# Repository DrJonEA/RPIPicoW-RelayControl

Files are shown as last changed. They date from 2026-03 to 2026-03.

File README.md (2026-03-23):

# DrJonEA: RPIPicoW-RelayControl

A Raspberry Pi Pico W based Relay control board. Using a ULN2003 as driver for a 5Volt Relay.

Example controlling the Relay via an onboard SPST switch. Plus remote control of MQTT/TLS.

This project is featured on my [Youtube Channel DrJonEA](https://youtube.com/@drjonea).

## Clone and Build
The example is built  using the Pico SDK version 2.2.0 and a number of libraries which are included as submodules.
Please clone the repository using the recurse submodules switch. 

I've written a [blog post](https://drjonea.co.uk/2025/12/15/building-my-projects-from-repo/) on how to clone, build and 
debug my projects. It covers command line and VSCode build. I hope this help you get started.

## Schematic, PCB Design and Components
The *PCB* folder contains the KiCAD project files for the PCB Design. 

Components:

 |  Designator | Footprint | Quantity | Designation | 
 | ------------- | ----------- | ----------- | ------------ | 
 | "Id" | "Designator" | "Footprint" | "Quantity" | "Designation" | "Supplier and ref" | 
 | 1 | "C1" | "CP_Radial_D10.0mm_P5.00mm" | 1 | "1000uF" | 
 | 2 | "I2C2,I2C1" | "PinHeader_1x04_P2.54mm_Vertical" | 2 | "Conn_01x04_Pin" | 
 | 3 | "J4,J3" | "PinHeader_1x04_P2.54mm_Vertical" | 2 | "Touch Display" | 
 | 4 | "O1" | "ScrewTerm_Oiyagai_01x02_5mm" | 1 | "Elect" | 
 | 5 | "A1" | "RaspberryPi_Pico_Common_Unspecified" | 1 | "RaspberryPi_Pico" | 
 | 6 | "C2" | "C_Disc_D4.7mm_W2.5mm_P5.00mm" | 1 | "10uF" | 
 | 7 | "K1" | "Relay_SPDT_SANYOU_SRD_Series_Form_C" | 1 | "SANYOU_SRD_Form_C" |  |  | 
 | 8 | "ST1" | "ScrewTerm_Oiyagai_01x03_5mm" | 1 | "Screw_Terminal_01x03" | 
 | 9 | "U1" | "CERDIP-16_W7.62mm_SideBrazed_LongPads_Socket" | 1 | "ULN2003" | 
 | 10 | "D1" | "D_DO-41_SOD81_P10.16mm_Horizontal" | 1 | "1N4007" | 
 | 11 | "SW2" | "SW_PUSH_6mm" | 1 | "SW_SPST" | 
 | 12 | "SW1" | "SW_Latch_7x7_DPDT" | 1 | "SW_DPDT_x2" | 
 | 13 | "R4" | "R_Axial_DIN0309_L9.0mm_D3.2mm_P15.24mm_Horizontal" | 1 | "220R" | 
 | 14 | "U2" | "WS2812B Strip" | 1 | 4 LED strip at 144per meter fits | 

## Examples Projects

### exp/TestLeds
A test project to check the WS2812B LEDs and Switch on the board

### exp/TestRelay
A test projec to check the Relay works. Uses the switch to toggle the relay state. Shows the state of the
relay on the WS2812B LED

### Main Project
This is a MQTT device connecting to a MQTT Broker (I use Flespi.io). It connects over TLS using WolfSSL 
to provide a TLS connection.  The device will then take commands on the topic 
"TNG/*{DEVICEID}*/TPC/Relay/req". With a Payload as JSON saying {"on": True} or {"on": False}.

To build this examples the following environment variables are used to source credentials:

+ WIFI_SSID
+ WIFI_PASSWORD
+ MQTT_CLIENT
+ MQTT_USER
+ MQTT_PASSWD
+ MQTT_HOST
+ MQTT_PORT

I have a course showing how I build these types of MQTT Devices over on [Udemy](https://www.udemy.com/course/iot-with-rpi-pico-w/?referralCode=331C13FDD6ABC00BFB81).

### Python Control Example
Python scripts which can interact with the device are included in the *py* folder. They require the client id of
the device the are controlling in this form:

python3 on.py *{DEVICE_ID}*

The scripts take credentials for the client from the followin environment variables:

+ MQTT_USER
+ MQTT_PASSWD
+ MQTT_HOST
+ MQTT_PORT

NOTE: To use MQTT the device and the client must have different Client IDs (or MQTT_USER).

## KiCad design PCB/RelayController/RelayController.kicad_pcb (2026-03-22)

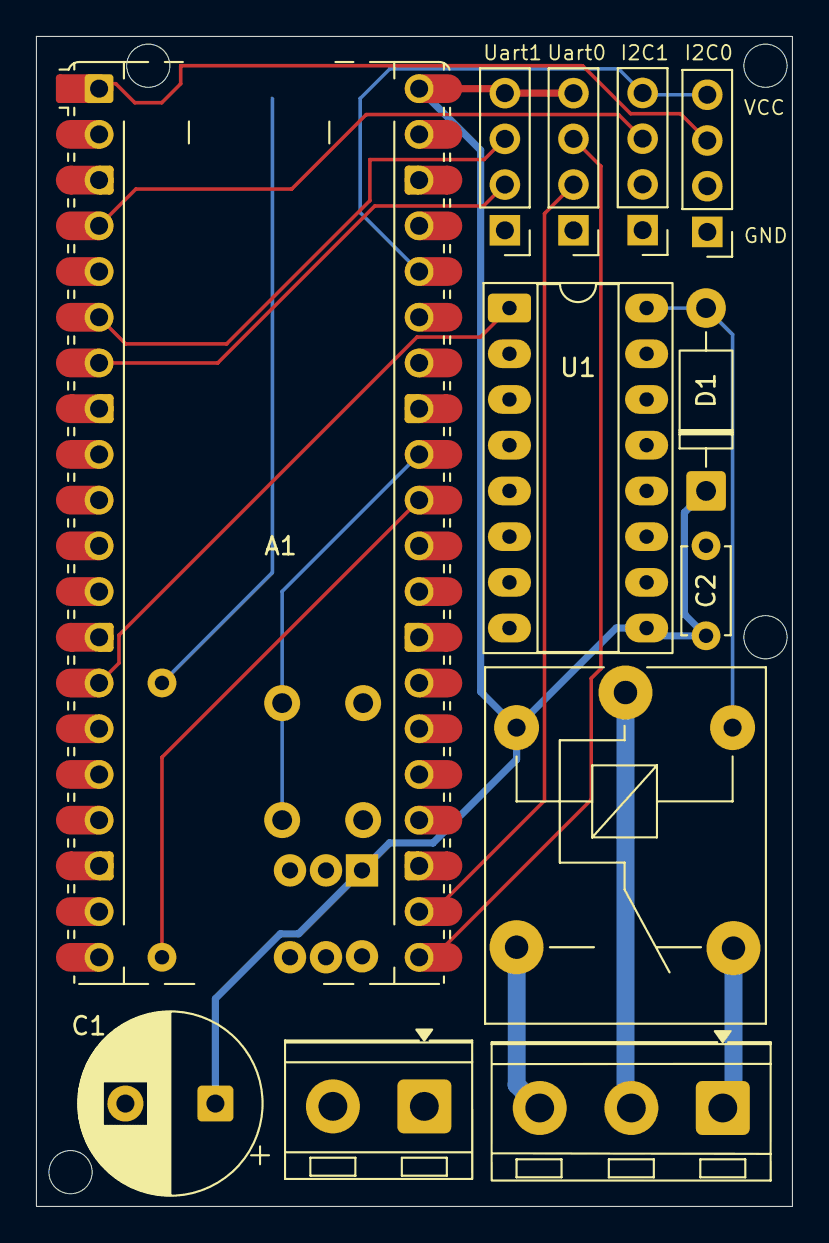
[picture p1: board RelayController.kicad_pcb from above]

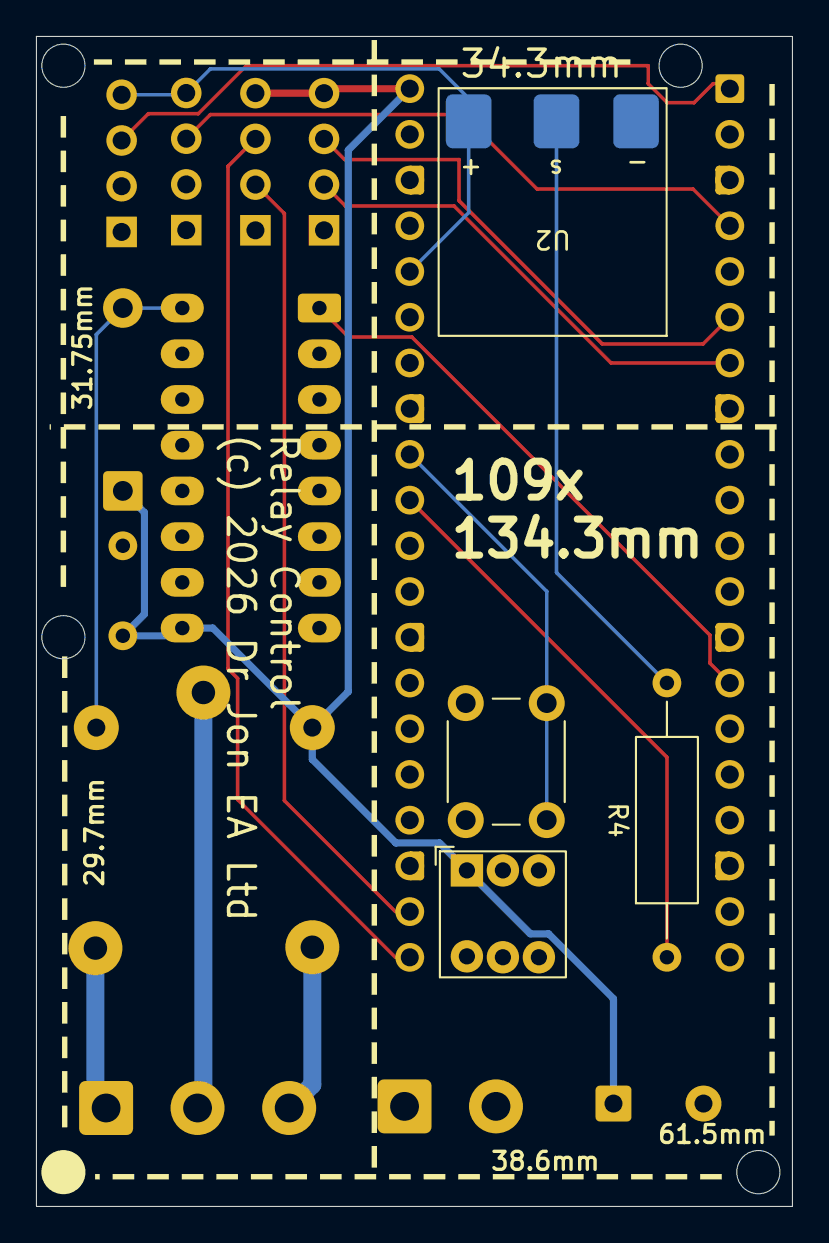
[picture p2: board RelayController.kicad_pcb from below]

Board: 4 copper layers, 42.0 x 65.0 mm, 16 parts (4 on the bottom side), 20 nets.

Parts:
A1: RaspberryPi_Pico; RaspberryPi_Pico_Common_Unspecified
C1: 1000uF; CP_Radial_D10.0mm_P5.00mm
C2: 10uF; C_Disc_D4.7mm_W2.5mm_P5.00mm
D1: 1N4007; D_DO-41_SOD81_P10.16mm_Horizontal
I2C1, I2C2: Conn_01x04_Pin; PinHeader_1x04_P2.54mm_Vertical
J3, J4: Touch Display; PinHeader_1x04_P2.54mm_Vertical
K1: SANYOU_SRD_Form_C; Relay_SPDT_SANYOU_SRD_Series_Form_C
O1: Elect; ScrewTerm_Oiyagai_01x02_5mm
R4: 220R; R_Axial_DIN0309_L9.0mm_D3.2mm_P15.24mm_Horizontal
ST1: Screw_Terminal_01x03; ScrewTerm_Oiyagai_01x03_5mm
SW1: SW_DPDT_x2; SW_Latch_7x7_DPDT
SW2: SW_SPST; SW_PUSH_6mm
U1: ULN2003; CERDIP-16_W7.62mm_SideBrazed_LongPads_Socket
U2: WS2812B Strip

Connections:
+3V3: A1.36 (3V3), I2C1.4 (VCC), I2C2.4 (VCC), U2.3 (VCC)
+5V: A1.40 (VBUS), C1.1, C2.1, D1.1 (K), J3.4, J4.4, K1.2, SW1.1 (A), U1.9 (COM)
/K1: A1.14 (GPIO10), U1.1 (I1)
/K1Coil: D1.2 (A), K1.5, U1.16 (O1)
/RX0: A1.22 (GPIO17), J4.2
/RX1: A1.7 (GPIO5), J3.2
/SW2: A1.32 (GPIO27_ADC1), SW2.2 (B)
/TX0: A1.21 (GPIO16), J4.3
/TX1: A1.6 (GPIO4), J3.3
/scl0: A1.2 (GPIO1), I2C1.2 (SCL)
/scl1: A1.5 (GPIO3), I2C2.2 (SCL)
/sda0: A1.1 (GPIO0), I2C1.3 (SDA)
/sda1: A1.4 (GPIO2), I2C2.3 (SDA)
GND: A1.3 (GND), A1.8 (GND), A1.13 (GND), A1.18 (GND), A1.23 (GND), A1.28 (GND), A1.38 (GND), C1.2, C2.2, I2C1.1 (GND), I2C2.1 (GND), J3.1, J4.1, O1.1, SW2.1 (A), U1.8 (GND), U2.1 (GND)
unnamed: A1.31 (GPIO26_ADC0), R4.1
unnamed: O1.2, SW1.2 (B)
unnamed: K1.4, ST1.1
unnamed: K1.1, ST1.2
unnamed: K1.3, ST1.3
unnamed: R4.2, U2.2 (In)

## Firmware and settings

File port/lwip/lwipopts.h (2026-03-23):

#ifndef __LWIPOPTS_H__
#define __LWIPOPTS_H__


#define TCPIP_THREAD_PRIO   2
#define TCPIP_THREAD_STACKSIZE 2048 //1024
#define DEFAULT_THREAD_STACKSIZE 1024
#define DEFAULT_RAW_RECVMBOX_SIZE 8
#define TCPIP_MBOX_SIZE 8
#define LWIP_TIMEVAL_PRIVATE 0

#define LWIP_SOCKET                 1
#define LWIP_SO_RCVBUF				1
#define RECV_BUFSIZE_DEFAULT		256
#define MEM_LIBC_MALLOC             0

#define MEM_ALIGNMENT               4
#define MEM_SIZE                    4000
#define MEMP_NUM_TCP_SEG            32
#define MEMP_NUM_ARP_QUEUE          10
#define PBUF_POOL_SIZE              24
#define LWIP_ARP                    1
#define LWIP_ETHERNET               1
#define LWIP_ICMP                   1
#define LWIP_RAW                    1
#define TCP_WND                     (8 * TCP_MSS)
#define TCP_MSS                     1460
#define TCP_SND_BUF                 (8 * TCP_MSS)
#define TCP_SND_QUEUELEN            ((4 * (TCP_SND_BUF) + (TCP_MSS - 1)) / (TCP_MSS))
#define LWIP_NETIF_STATUS_CALLBACK  1
#define LWIP_NETIF_LINK_CALLBACK    1
#define LWIP_NETIF_HOSTNAME         1
#define LWIP_NETCONN                1
#define MEM_STATS                   0
#define SYS_STATS                   0
#define MEMP_STATS                  0
#define LINK_STATS                  0
// #define ETH_PAD_SIZE                2
#define LWIP_CHKSUM_ALGORITHM       3
#define LWIP_DHCP                   1
#define LWIP_IPV4                   1
#define LWIP_TCP                    1
#define LWIP_UDP                    1
#define LWIP_DNS                    1
#define LWIP_TCP_KEEPALIVE          1
#define LWIP_NETIF_TX_SINGLE_PBUF   1
#define DHCP_DOES_ARP_CHECK         1
#define LWIP_DHCP_DOES_ACD_CHECK    0

#ifndef NDEBUG
#define LWIP_DEBUG                  1
#define LWIP_STATS                  1
#define LWIP_STATS_DISPLAY          1
#endif

#define ETHARP_DEBUG                LWIP_DBG_OFF
#define NETIF_DEBUG                 LWIP_DBG_OFF
#define PBUF_DEBUG                  LWIP_DBG_OFF
#define API_LIB_DEBUG               LWIP_DBG_OFF
#define API_MSG_DEBUG               LWIP_DBG_OFF
#define SOCKETS_DEBUG               LWIP_DBG_OFF
#define ICMP_DEBUG                  LWIP_DBG_OFF
#define INET_DEBUG                  LWIP_DBG_OFF
#define IP_DEBUG                    LWIP_DBG_OFF
#define IP_REASS_DEBUG              LWIP_DBG_OFF
#define RAW_DEBUG                   LWIP_DBG_OFF
#define MEM_DEBUG                   LWIP_DBG_OFF
#define MEMP_DEBUG                  LWIP_DBG_OFF
#define SYS_DEBUG                   LWIP_DBG_OFF
#define TCP_DEBUG                   LWIP_DBG_OFF
#define TCP_INPUT_DEBUG             LWIP_DBG_OFF
#define TCP_OUTPUT_DEBUG            LWIP_DBG_OFF
#define TCP_RTO_DEBUG               LWIP_DBG_OFF
#define TCP_CWND_DEBUG              LWIP_DBG_OFF
#define TCP_WND_DEBUG               LWIP_DBG_OFF
#define TCP_FR_DEBUG                LWIP_DBG_OFF
#define TCP_QLEN_DEBUG              LWIP_DBG_OFF
#define TCP_RST_DEBUG               LWIP_DBG_OFF
#define UDP_DEBUG                   LWIP_DBG_OFF
#define TCPIP_DEBUG                 LWIP_DBG_OFF
#define PPP_DEBUG                   LWIP_DBG_OFF
#define SLIP_DEBUG                  LWIP_DBG_OFF
#define DHCP_DEBUG                  LWIP_DBG_OFF


#define DEFAULT_TCP_RECVMBOX_SIZE 128



#endif /* __LWIPOPTS_H__ */

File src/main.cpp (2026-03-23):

/***
 * main.cpp - MQTT Connection
 * Jon Durrant
 * 4-Oct-2022
 *
 *
 */

#include "pico/cyw43_arch.h"
#include "pico/stdlib.h"
#include <stdio.h>

#include "lwip/ip4_addr.h"
#include "lwip/sockets.h"
#include "lwip/dns.h"

#include "FreeRTOS.h"
#include "task.h"
#include <stdio.h>


#include "WifiHelper.h"
#include "MQTTAgent.h"
#include "MQTTAgentObserver.h"
#include "RelayAgent.h"
#include "MQTTRouterRelay.h"
#include "RelayControllerState.h"
#include "TwinTask.h"
#include "MQTTPingTask.h"
#include "TLSTransBlock.h"
#include "wolfssl/ssl.h"

#include "RelayControlBoard.h"


//Check these definitions where added from the makefile
#ifndef WIFI_SSID
#error "WIFI_SSID not defined"
#endif
#ifndef WIFI_PASSWORD
#error "WIFI_PASSWORD not defined"
#endif
#ifndef MQTT_CLIENT
#error "MQTT_CLIENT not defined"
#endif
#ifndef MQTT_USER
#error "MQTT_PASSWD not defined"
#endif
#ifndef MQTT_PASSWD
#error "MQTT_PASSWD not defined"
#endif
#ifndef MQTT_HOST
#error "MQTT_HOST not defined"
#endif
#ifndef MQTT_PORT
#error "MQTT_PORT not defined"
#endif




#define TASK_PRIORITY			( tskIDLE_PRIORITY + 1UL )


void runTimeStats(   ){
	TaskStatus_t *pxTaskStatusArray;
	volatile UBaseType_t uxArraySize, x;
	unsigned long ulTotalRunTime;


   /* Take a snapshot of the number of tasks in case it changes while this
   function is executing. */
   uxArraySize = uxTaskGetNumberOfTasks();
   printf("Number of tasks %d\n", uxArraySize);

   /* Allocate a TaskStatus_t structure for each task.  An array could be
   allocated statically at compile time. */
   pxTaskStatusArray = (TaskStatus_t *)pvPortMalloc( uxArraySize * sizeof( TaskStatus_t ) );

   if( pxTaskStatusArray != NULL ){
      /* Generate raw status information about each task. */
      uxArraySize = uxTaskGetSystemState( pxTaskStatusArray,
                                 uxArraySize,
                                 &ulTotalRunTime );



	 /* For each populated position in the pxTaskStatusArray array,
	 format the raw data as human readable ASCII data. */
	 for( x = 0; x < uxArraySize; x++ )
	 {
		 printf("Task: %d \t cPri:%d \t bPri:%d \t hw:%d \t%s\n",
				pxTaskStatusArray[ x ].xTaskNumber ,
				pxTaskStatusArray[ x ].uxCurrentPriority ,
				pxTaskStatusArray[ x ].uxBasePriority ,
				pxTaskStatusArray[ x ].usStackHighWaterMark ,
				pxTaskStatusArray[ x ].pcTaskName
				);
	 }


      /* The array is no longer needed, free the memory it consumes. */
      vPortFree( pxTaskStatusArray );
   } else {
	   printf("Fairelay to allocate space for stats\n");
   }

   HeapStats_t heapStats;
   vPortGetHeapStats(&heapStats);
   printf("HEAP avl: %d, blocks %d, alloc: %d, free: %d\n",
		   heapStats.xAvailableHeapSpaceInBytes,
		   heapStats.xNumberOfFreeBlocks,
		   heapStats.xNumberOfSuccessfulAllocations,
		   heapStats.xNumberOfSuccessfulFrees
		   );

}

void debugCB(const int logLevel, const char *const logMessage){
	printf("WOLFSSL DEBUG(%d): %s\n", logLevel, logMessage);
}


void main_task(void *params){

	printf("Main task started\n");

	//Init WolfSSL
	wolfSSL_Init();
	wolfSSL_SetLoggingCb( debugCB);
	//wolfSSL_Debugging_ON();

	if (WifiHelper::init()){
		printf("Wifi Controller Initialised\n");
	} else {
		printf("Failed to initialise controller\n");
		return;
	}


	printf("Connecting to WiFi... %s \n", WIFI_SSID);

	if (WifiHelper::join(WIFI_SSID, WIFI_PASSWORD)){
		printf("Connect to Wifi\n");
	} else {
		printf("Failed to connect to Wifi \n");
	}


	//Print MAC Address
	char macStr[20];
	WifiHelper::getMACAddressStr(macStr);
	printf("MAC ADDRESS: %s\n", macStr);

	//Print IP Address
	char ipStr[20];
	WifiHelper::getIPAddressStr(ipStr);
	printf("IP ADDRESS: %s\n", ipStr);


	// Setup for MQTT Connection
	char mqttTarget[] = MQTT_HOST;
	int mqttPort = MQTT_PORT;
	char mqttClient[] = MQTT_CLIENT;
	char mqttUser[] = MQTT_USER;
	char mqttPwd[] = MQTT_PASSWD;

	MQTTAgent mqttAgent;
	MQTTAgentObserver mqttObs;
	TLSTransBlock transport;

	mqttAgent.setObserver(&mqttObs);
	mqttAgent.setTransport(&transport);
	mqttAgent.credentials(mqttUser, mqttPwd, mqttClient);

	printf("Connecting to: %s(%d)\n", mqttTarget, mqttPort);
	printf("Client id: %.4s...\n", mqttAgent.getId());
	printf("User id: %.4s...\n", mqttUser);

	mqttAgent.mqttConnect(mqttTarget, mqttPort, true);
	mqttAgent.start(TASK_PRIORITY);

	RelayControllerState relayState;
	TwinTask twinTask;
	twinTask.setStateObject(&relayState);
	twinTask.setMQTTInterface(&mqttAgent);
	twinTask.start(TASK_PRIORITY);

	RelayAgent relayAgent(RELAY_K1, SW2_GP, &mqttAgent, &relayState);
	relayAgent.start("RelayAgent", TASK_PRIORITY);

	MQTTRouterRelay router(&relayAgent);
	MQTTPingTask xPing;
	xPing.setInterface(&mqttAgent);
	xPing.start(TASK_PRIORITY);
	router.setPingTask(&xPing, &mqttAgent);
	router.setTwin(&twinTask);
	mqttAgent.setRouter(&router);


    while(true) {

    	//runTimeStats();

        vTaskDelay(3000);

        if (!WifiHelper::isJoined()){
        	printf("AP Link is down\n");

        	if (WifiHelper::join(WIFI_SSID, WIFI_PASSWORD)){
				printf("Connect to Wifi\n");
			} else {
				printf("Failed to connect to Wifi \n");
			}
        }


    }

}





void vLaunch( void) {
    TaskHandle_t task;

    xTaskCreate(main_task, "MainThread", 2048, NULL, TASK_PRIORITY, &task);

    /* Start the tasks and timer running. */
    vTaskStartScheduler();
}


int main( void )
{
    stdio_init_all();
    sleep_ms(2000);
    printf("GO\n");

    /* Configure the hardware ready to run the demo. */
    const char *rtos_name;
    rtos_name = "FreeRTOS";
    printf("Starting %s on core 0:\n", rtos_name);
    vLaunch();

    return 0;
}

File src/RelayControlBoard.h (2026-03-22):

/***
 * Configuration for Relay Control Board
 */

#ifndef RelayControlBoard_H
#define RelayControlBoard_H

#include "pico/stdlib.h"


#define NEOPIXELS_PIN 26
#define NEOPIXELS_LEN 4

#define SW2_GP 27

#define RELAY_K1 10


#define SDA0 0
#define SCL0 1
#define SDA1 2
#define SCL1 3

#define SPI SPI0
#define SPI_SCK 6
#define SPI_TX 7
#define SPI_RX 8
#define SPI_CS 9

#define UART0_TX 16
#define UART0_RX 17
#define UART0_BAUDRATE 115200

#define UART1_TX 4
#define UART1_RX 5
#define UART1_BAUDRATE 115200



#endif

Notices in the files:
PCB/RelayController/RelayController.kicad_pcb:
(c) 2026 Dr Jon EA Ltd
